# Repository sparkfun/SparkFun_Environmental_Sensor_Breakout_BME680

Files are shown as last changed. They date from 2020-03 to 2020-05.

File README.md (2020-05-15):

SparkFun Environmental Sensor - BME680 (Qwiic)
========================================

SparkFun Environmental Sensor - BME680 (Qwiic) (https://www.sparkfun.com/products/16466)

[*SparkFun Environmental Sensor - BME680 (Qwiic) (SEN-16466)*](https://www.sparkfun.com/products/16466)

The Environmental Sensor - BME680 (Qwiic) is a powerful 4-in-1 environmental sensor that communicates over I<sup>2</sup>C or SPI. The BME680 combines a gas sensor with temperature, humidity and barometric pressure sensors for a complete environmental sensor in a tiny package.

Repository Contents
-------------------
* **/Hardware** - Eagle design files (.brd, .sch)
* **/Production** - Production panel files (.brd)

Documentation
--------------
* **[Hookup Guide](https://learn.sparkfun.com/tutorials/environmental-sensor---bme680-qwiic-hookup-guide)** - Basic hookup guide for the SparkFun Environmental Sensor - BME680 (Qwiic).
* **[BME680 Arduino Library](https://github.com/SV-Zanshin/BME680)** - Arduino library created by SV-Zanshin for the BME680 Environmental Sensor.
* **[SparkFun Fritzing repo](https://github.com/sparkfun/Fritzing_Parts)** - Fritzing diagrams for SparkFun products.
* **[SparkFun 3D Model repo](https://github.com/sparkfun/3D_Models)** - 3D models of SparkFun products. 

Product Versions
----------------
* [SPX-14570](https://www.sparkfun.com/products/14570)- Original SparkX Release.
* [SEN-16466](https://www.sparkfun.com/products/16466)- SparkFun release.

License Information
-------------------

This product is _**open source**_! 

Please review the LICENSE.md file for license information. 

If you have any questions or concerns on licensing, please contact technical support on our [SparkFun forums](https://forum.sparkfun.com/viewforum.php?f=152).

Distributed as-is; no warranty is given.

- Your friends at SparkFun.

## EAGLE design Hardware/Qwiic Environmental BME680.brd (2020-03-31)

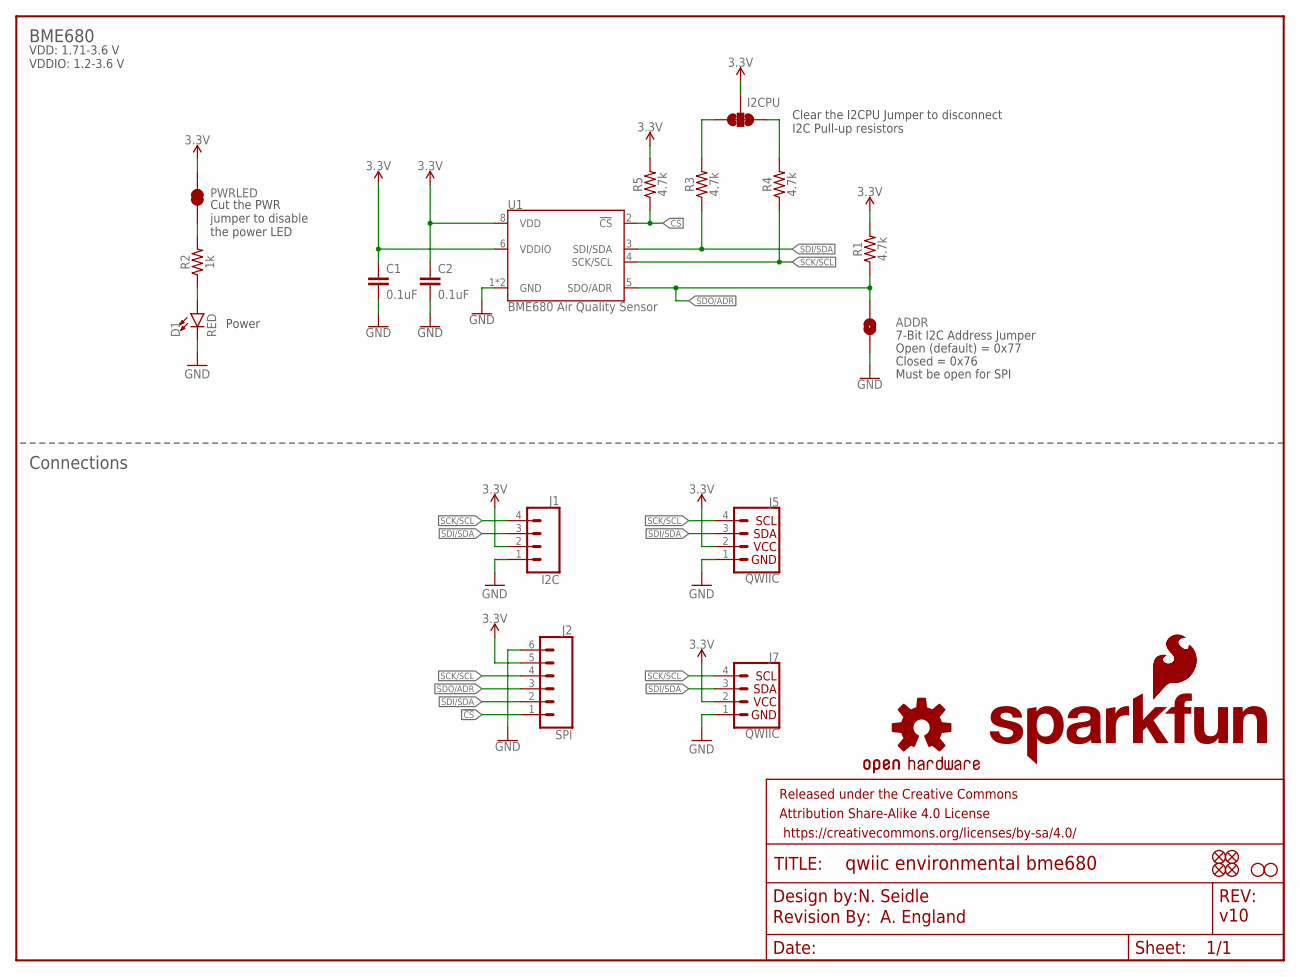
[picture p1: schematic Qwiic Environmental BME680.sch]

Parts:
ADDR: JUMPER-SMT_2_NO_SILK; SMT-JUMPER_2_NO_SILK
C1, C2: 0.1uF; 0603
D1: RED; LED-0603
FD1, FD2, FD3, FD4: FIDUCIALUFIDUCIAL; FIDUCIAL-MICRO
FRAME1: FRAME-LETTER; CREATIVE_COMMONS
H1, H2: STAND-OFFTIGHT; STAND-OFF-TIGHT
I2CPU: I2C PU; SMT-JUMPER_3_2-NC_TRACE_SILK
J1: I2C; 1X04_NO_SILK
J2: SPI; 1X06_NO_SILK
J5, J7: QWIIC; JST04_1MM_RA
LOGO1: OSHW-LOGOMINI; OSHW-LOGO-MINI
LOGO2: SFE_LOGO_NAME_FLAME.1_INCH; SFE_LOGO_NAME_FLAME_.1
LOGO3: REVISION
LOGO4: SFE_LOGO_FLAME.1_INCH; SFE_LOGO_FLAME_.1
PWRLED: JUMPER-SMT_2_NC_TRACE_SILK; SMT-JUMPER_2_NC_TRACE_SILK
R1, R3, R4, R5: 4.7k; 0603@1
R2: 1k; 0603
U1: BME680 Air Quality Sensor; LGA3.0X3.0

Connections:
3.3V: C1.1, C2.1, I2CPU.2, J1.2, J2.5, J5.2, J7.2, PWRLED.2, R1.2, R5.2, U1.6 (VDDIO), U1.8 (VDD)
!CS: J2.1, R5.1, U1.2 (!CS)
GND: ADDR.1, C1.2, C2.2, D1.C, J1.1, J2.6, J5.1, J7.1, U1.1 (GND), U1.7 (GND)
unnamed: PWRLED.1, R2.2
unnamed: D1.A, R2.1
unnamed: I2CPU.3, R3.2
unnamed: I2CPU.1, R4.2
SCK/SCL: J1.4, J2.4, J5.4, J7.4, R4.1, U1.4 (SCK/SCL)
SDI/SDA: J1.3, J2.2, J5.3, J7.3, R3.1, U1.3 (SDI/SDA)
SDO/ADR: ADDR.2, J2.3, R1.1, U1.5 (SDO/ADR)

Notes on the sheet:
v10
7-Bit I2C Address Jumper
Open (default) = 0x77
Closed = 0x76
N. Seidle
BME680
Connections
A. England
VDD: 1.71-3.6 V VDDIO: 1.2-3.6 V
Must be open for SPI
Clear the I2CPU Jumper to disconnect I2C Pull-up resistors
Power
Cut the PWR jumper to disable the power LED

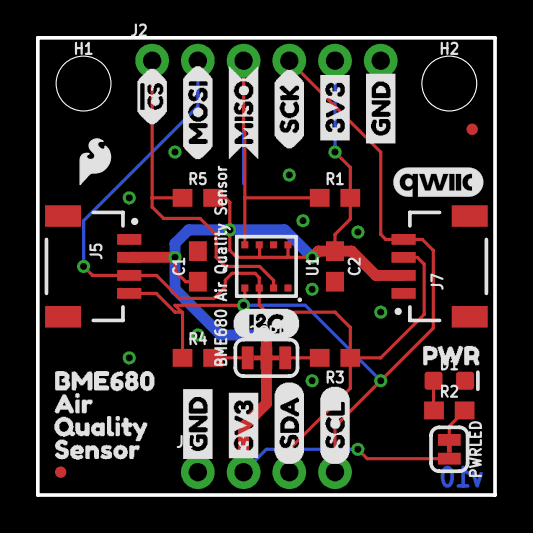
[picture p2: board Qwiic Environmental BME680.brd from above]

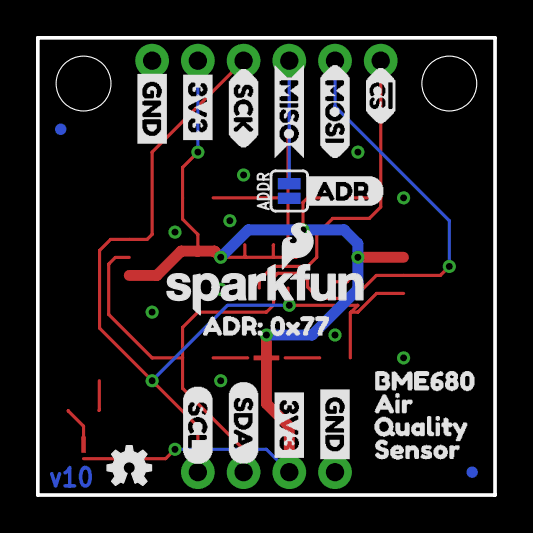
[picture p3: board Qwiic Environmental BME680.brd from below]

Board: 2 copper layers, 25.4 x 25.4 mm, 60 parts (21 on the bottom side), 10 nets.

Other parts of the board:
U$1, U$2: MISO_O
U$3, U$4: !CS_I
U$5, U$6: MOSI_I
U$7, U$8: SCK_I
U$9, U$10, U$16, U$17: 3V3_P
U$11, U$12, U$13, U$14: GND_P
U$15: I2C
U$18, U$19: SDA_IO
U$20, U$21: SCL_IO
U$22, U$26: BME6800
U$23, U$27: AIR1
U$24, U$28: QUALITY2
U$25, U$29: SENSOR3
U$30: ADR4
U$32: QWIIC_5MM
U$33: ADR#_0X770
U$34: PWR_TO

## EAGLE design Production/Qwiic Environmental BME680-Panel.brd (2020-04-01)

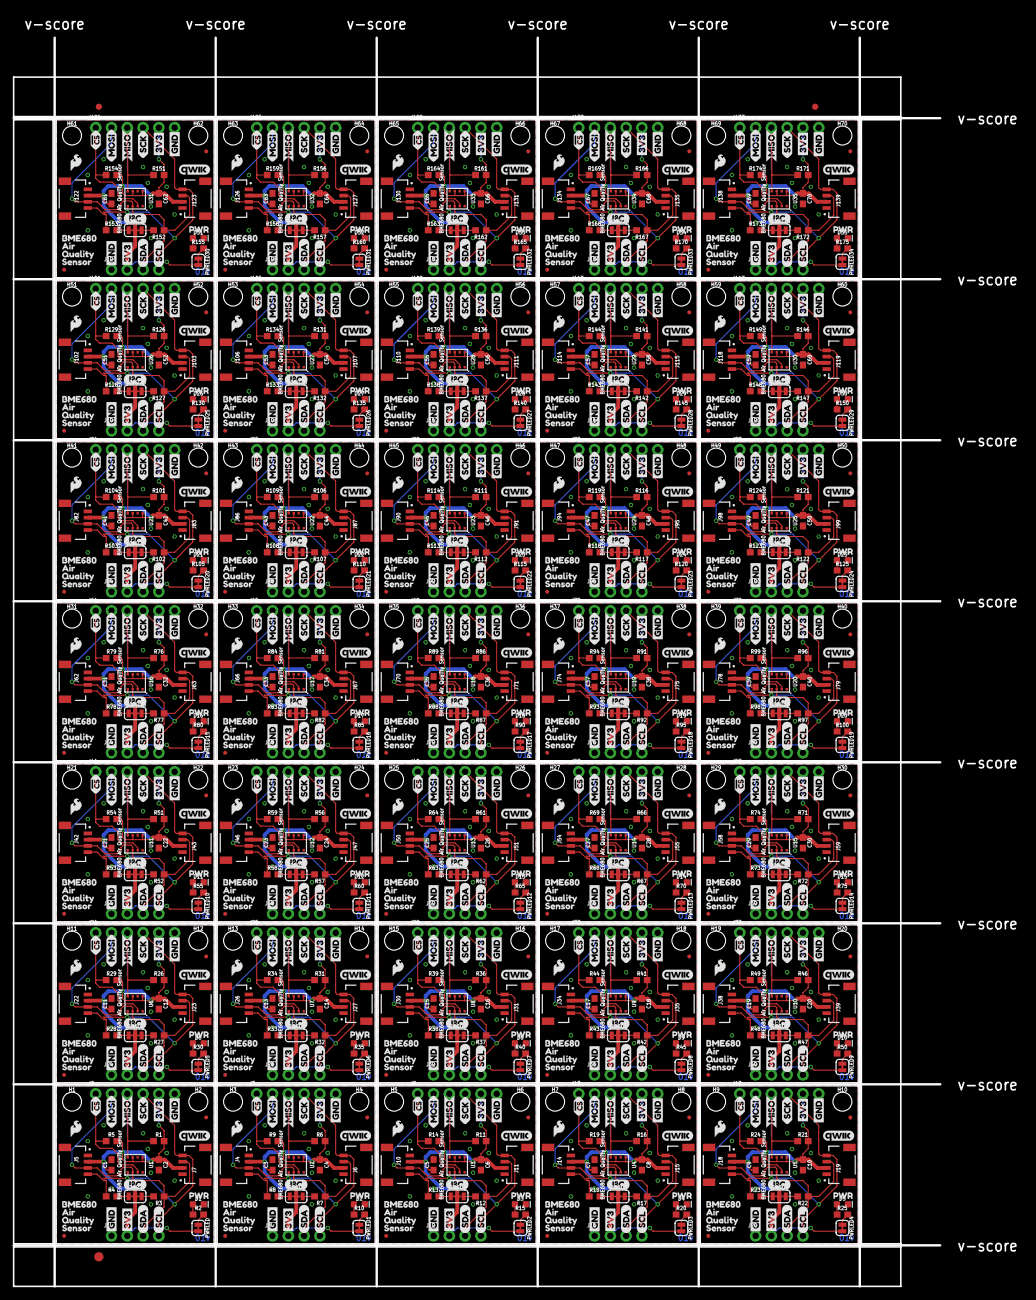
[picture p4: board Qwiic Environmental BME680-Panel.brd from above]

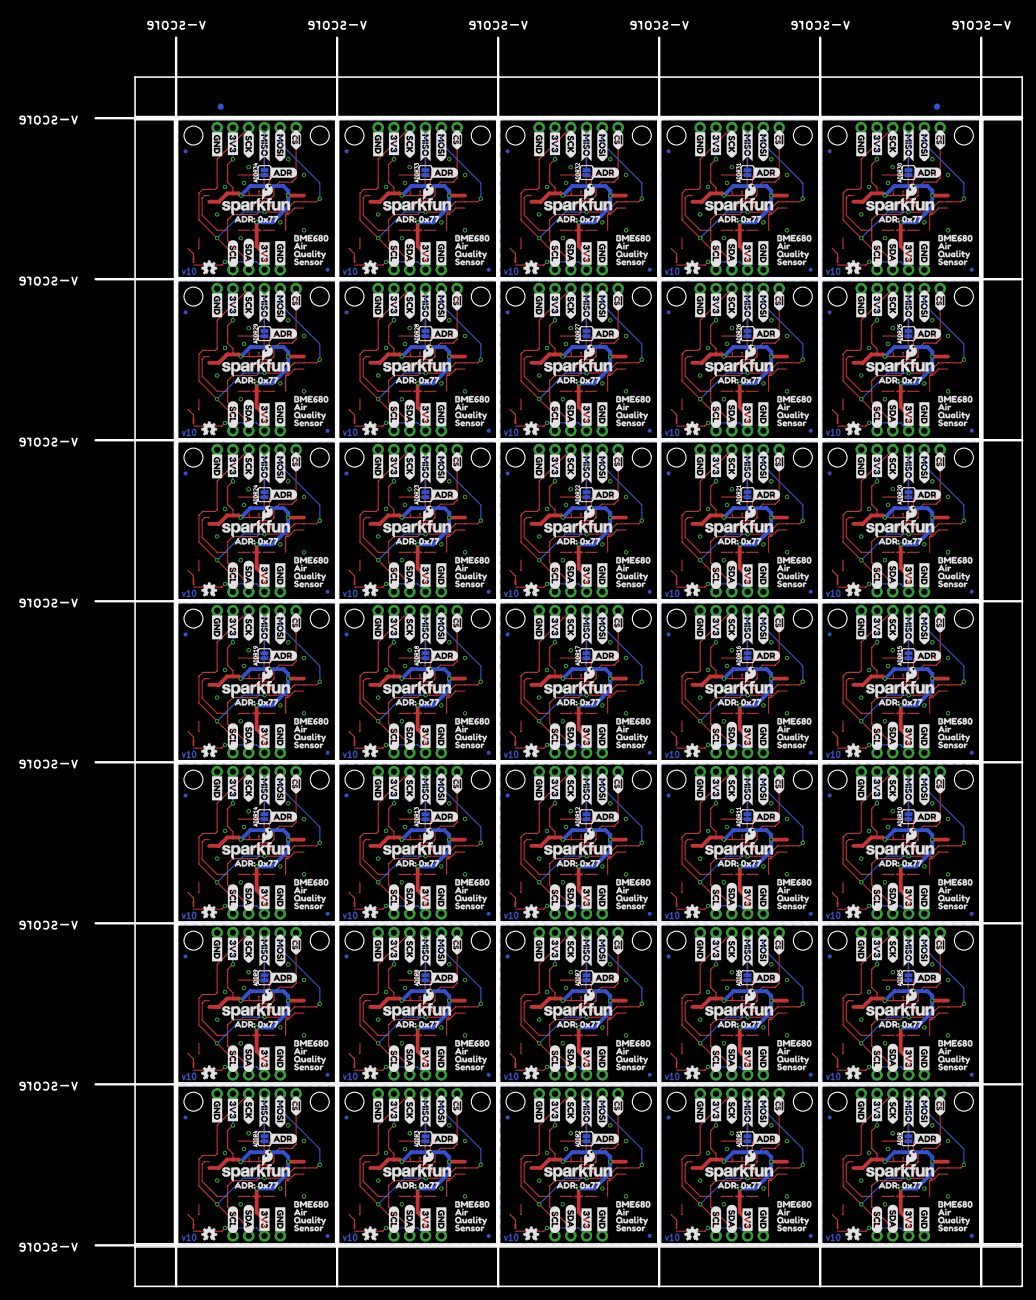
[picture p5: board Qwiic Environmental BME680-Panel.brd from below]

Board: 2 copper layers, 149.1 x 200.9 mm, 2070 parts (737 on the bottom side), 350 nets.

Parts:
ADDR, ADDR1, ADDR2, ADDR3, ADDR4, ADDR5, ADDR6, ADDR7, ADDR8, ADDR9, ADDR10, ADDR11, ADDR12, ADDR13, ADDR14, ADDR15, ADDR16, ADDR17, ADDR18, ADDR19, ADDR20, ADDR21, ADDR22, ADDR23, ADDR24, ADDR25, ADDR26, ADDR27, ADDR28, ADDR29, ADDR30, ADDR31, ADDR32, ADDR33, ADDR34: JUMPER-SMT_2_NO_SILK; SMT-JUMPER_2_NO_SILK
C1, C2, C3, C4, C5, C6, C7, C8, C9, C10, C11, C12, C13, C14, C15, C16, C17, C18, C19, C20, C21, C22, C23, C24, C25, C26, C27, C28, C29, C30, C31, C32, C33, C34, C35, C36, C37, C38, C39, C40, C41, C42, C43, C44, C45, C46, C47, C48, C49, C50, C51, C52, C53, C54, C55, C56, C57, C58, C59, C60, C61, C62, C63, C64, C65, C66, C67, C68, C69, C70: 0.1uF; 0603
D1, D2, D3, D4, D5, D6, D7, D8, D9, D10, D11, D12, D13, D14, D15, D16, D17, D18, D19, D20, D21, D22, D23, D24, D25, D26, D27, D28, D29, D30, D31, D32, D33, D34, D35: RED; LED-0603
E$1, E$2, E$3, E$4: FIDUCIAL-1X2
E$5: FIDUCIAL-1.5X3
FD1, FD2, FD3, FD4, FD5, FD6, FD7, FD8, FD9, FD10, FD11, FD12, FD13, FD14, FD15, FD16, FD17, FD18, FD19, FD20, FD21, FD22, FD23, FD24, FD25, FD26, FD27, FD28, FD29, FD30, FD31, FD32, FD33, FD34, FD35, FD36, FD37, FD38, FD39, FD40, FD41, FD42, FD43, FD44, FD45, FD46, FD47, FD48, FD49, FD50, FD51, FD52, FD53, FD54, FD55, FD56, FD57, FD58, FD59, FD60, FD61, FD62, FD63, FD64, FD65, FD66, FD67, FD68, FD69, FD70, FD71, FD72, FD73, FD74, FD75, FD76, FD77, FD78, FD79, FD80, FD81, FD82, FD83, FD84, FD85, FD86, FD87, FD88, FD89, FD90, FD91, FD92, FD93, FD94, FD95, FD96, FD97, FD98, FD99, FD100, FD101, FD102, FD103, FD104, FD105, FD106, FD107, FD108, FD109, FD110, FD111, FD112, FD113, FD114, FD115, FD116, FD117, FD118, FD119, FD120, FD121, FD122, FD123, FD124, FD125, FD126, FD127, FD128, FD129, FD130, FD131, FD132, FD133, FD134, FD135, FD136, FD137, FD138, FD139, FD140: FIDUCIALUFIDUCIAL; FIDUCIAL-MICRO
H1, H2, H3, H4, H5, H6, H7, H8, H9, H10, H11, H12, H13, H14, H15, H16, H17, H18, H19, H20, H21, H22, H23, H24, H25, H26, H27, H28, H29, H30, H31, H32, H33, H34, H35, H36, H37, H38, H39, H40, H41, H42, H43, H44, H45, H46, H47, H48, H49, H50, H51, H52, H53, H54, H55, H56, H57, H58, H59, H60, H61, H62, H63, H64, H65, H66, H67, H68, H69, H70: STAND-OFFTIGHT; STAND-OFF-TIGHT
I2CPU, I2CPU1, I2CPU2, I2CPU3, I2CPU4, I2CPU5, I2CPU6, I2CPU7, I2CPU8, I2CPU9, I2CPU10, I2CPU11, I2CPU12, I2CPU13, I2CPU14, I2CPU15, I2CPU16, I2CPU17, I2CPU18, I2CPU19, I2CPU20, I2CPU21, I2CPU22, I2CPU23, I2CPU24, I2CPU25, I2CPU26, I2CPU27, I2CPU28, I2CPU29, I2CPU30, I2CPU31, I2CPU32, I2CPU33, I2CPU34: I2C PU; SMT-JUMPER_3_2-NC_TRACE_SILK
J1, J8, J12, J16, J20, J24, J28, J32, J36, J40, J44, J48, J52, J56, J60, J64, J68, J72, J76, J80, J84, J88, J92, J96, J100, J104, J108, J112, J116, J120, J124, J128, J132, J136, J140: I2C; 1X04_NO_SILK
J2, J3, J9, J13, J17, J21, J25, J29, J33, J37, J41, J45, J49, J53, J57, J61, J65, J69, J73, J77, J81, J85, J89, J93, J97, J101, J105, J109, J113, J117, J121, J125, J129, J133, J137: SPI; 1X06_NO_SILK
J4, J5, J6, J7, J10, J11, J14, J15, J18, J19, J22, J23, J26, J27, J30, J31, J34, J35, J38, J39, J42, J43, J46, J47, J50, J51, J54, J55, J58, J59, J62, J63, J66, J67, J70, J71, J74, J75, J78, J79, J82, J83, J86, J87, J90, J91, J94, J95, J98, J99, J102, J103, J106, J107, J110, J111, J114, J115, J118, J119, J122, J123, J126, J127, J130, J131, J134, J135, J138, J139: QWIIC; JST04_1MM_RA
LOGO1, LOGO5, LOGO9, LOGO13, LOGO17, LOGO21, LOGO25, LOGO29, LOGO33, LOGO37, LOGO41, LOGO45, LOGO49, LOGO53, LOGO57, LOGO61, LOGO65, LOGO69, LOGO73, LOGO77, LOGO81, LOGO85, LOGO89, LOGO93, LOGO97, LOGO101, LOGO105, LOGO109, LOGO113, LOGO117, LOGO121, LOGO125, LOGO129, LOGO133, LOGO137: OSHW-LOGOMINI; OSHW-LOGO-MINI
LOGO2, LOGO7, LOGO11, LOGO15, LOGO19, LOGO23, LOGO27, LOGO31, LOGO35, LOGO39, LOGO43, LOGO47, LOGO51, LOGO55, LOGO59, LOGO63, LOGO67, LOGO71, LOGO75, LOGO79, LOGO83, LOGO87, LOGO91, LOGO95, LOGO99, LOGO103, LOGO107, LOGO111, LOGO115, LOGO119, LOGO123, LOGO127, LOGO131, LOGO135, LOGO139: SFE_LOGO_NAME_FLAME.1_INCH; SFE_LOGO_NAME_FLAME_.1
LOGO3, LOGO6, LOGO10, LOGO14, LOGO18, LOGO22, LOGO26, LOGO30, LOGO34, LOGO38, LOGO42, LOGO46, LOGO50, LOGO54, LOGO58, LOGO62, LOGO66, LOGO70, LOGO74, LOGO78, LOGO82, LOGO86, LOGO90, LOGO94, LOGO98, LOGO102, LOGO106, LOGO110, LOGO114, LOGO118, LOGO122, LOGO126, LOGO130, LOGO134, LOGO138: REVISION
LOGO4, LOGO8, LOGO12, LOGO16, LOGO20, LOGO24, LOGO28, LOGO32, LOGO36, LOGO40, LOGO44, LOGO48, LOGO52, LOGO56, LOGO60, LOGO64, LOGO68, LOGO72, LOGO76, LOGO80, LOGO84, LOGO88, LOGO92, LOGO96, LOGO100, LOGO104, LOGO108, LOGO112, LOGO116, LOGO120, LOGO124, LOGO128, LOGO132, LOGO136, LOGO140: SFE_LOGO_FLAME.1_INCH; SFE_LOGO_FLAME_.1
PWRLED, PWRLED1, PWRLED2, PWRLED3, PWRLED4, PWRLED5, PWRLED6, PWRLED7, PWRLED8, PWRLED9, PWRLED10, PWRLED11, PWRLED12, PWRLED13, PWRLED14, PWRLED15, PWRLED16, PWRLED17, PWRLED18, PWRLED19, PWRLED20, PWRLED21, PWRLED22, PWRLED23, PWRLED24, PWRLED25, PWRLED26, PWRLED27, PWRLED28, PWRLED29, PWRLED30, PWRLED31, PWRLED32, PWRLED33, PWRLED34: JUMPER-SMT_2_NC_TRACE_SILK; SMT-JUMPER_2_NC_TRACE_SILK
R1, R3, R4, R5, R6, R7, R8, R9, R11, R12, R13, R14, R16, R17, R18, R19, R21, R22, R23, R24, R26, R27, R28, R29, R31, R32, R33, R34, R36, R37, R38, R39, R41, R42, R43, R44, R46, R47, R48, R49, R51, R52, R53, R54, R56, R57, R58, R59, R61, R62, R63, R64, R66, R67, R68, R69, R71, R72, R73, R74, R76, R77, R78, R79, R81, R82, R83, R84, R86, R87, R88, R89, R91, R92, R93, R94, R96, R97, R98, R99, R101, R102, R103, R104, R106, R107, R108, R109, R111, R112, R113, R114, R116, R117, R118, R119, R121, R122, R123, R124, R126, R127, R128, R129, R131, R132, R133, R134, R136, R137, R138, R139, R141, R142, R143, R144, R146, R147, R148, R149, R151, R152, R153, R154, R156, R157, R158, R159, R161, R162, R163, R164, R166, R167, R168, R169, R171, R172, R173, R174: 4.7k; 0603@1
R2, R10, R15, R20, R25, R30, R35, R40, R45, R50, R55, R60, R65, R70, R75, R80, R85, R90, R95, R100, R105, R110, R115, R120, R125, R130, R135, R140, R145, R150, R155, R160, R165, R170, R175: 1k; 0603
U1, U2, U3, U4, U5, U6, U7, U8, U9, U10, U11, U12, U13, U14, U15, U16, U17, U18, U19, U20, U21, U22, U23, U24, U25, U26, U27, U28, U29, U30, U31, U32, U33, U34, U35: BME680 Air Quality Sensor; LGA3.0X3.0
U$1, U$2, U$38, U$39, U$71, U$72, U$104, U$105, U$137, U$138, U$170, U$171, U$203, U$204, U$236, U$237, U$269, U$270, U$302, U$303, U$335, U$336, U$368, U$369, U$401, U$402, U$434, U$435, U$467, U$468, U$500, U$501, U$533, U$534, U$566, U$567, U$599, U$600, U$632, U$633, U$665, U$666, U$698, U$699, U$731, U$732, U$764, U$765, U$797, U$798, U$830, U$831, U$863, U$864, U$896, U$897, U$929, U$930, U$962, U$963, U$995, U$996, U$1028, U$1029, U$1061, U$1062, U$1094, U$1095, U$1127, U$1128: MISO_O
U$3, U$4, U$31, U$35, U$67, U$68, U$100, U$101, U$133, U$134, U$166, U$167, U$199, U$200, U$232, U$233, U$265, U$266, U$298, U$299, U$331, U$332, U$364, U$365, U$397, U$398, U$430, U$431, U$463, U$464, U$496, U$497, U$529, U$530, U$562, U$563, U$595, U$596, U$628, U$629, U$661, U$662, U$694, U$695, U$727, U$728, U$760, U$761, U$793, U$794, U$826, U$827, U$859, U$860, U$892, U$893, U$925, U$926, U$958, U$959, U$991, U$992, U$1024, U$1025, U$1057, U$1058, U$1090, U$1091, U$1123, U$1124: !CS_I
U$5, U$6, U$36, U$37, U$69, U$70, U$102, U$103, U$135, U$136, U$168, U$169, U$201, U$202, U$234, U$235, U$267, U$268, U$300, U$301, U$333, U$334, U$366, U$367, U$399, U$400, U$432, U$433, U$465, U$466, U$498, U$499, U$531, U$532, U$564, U$565, U$597, U$598, U$630, U$631, U$663, U$664, U$696, U$697, U$729, U$730, U$762, U$763, U$795, U$796, U$828, U$829, U$861, U$862, U$894, U$895, U$927, U$928, U$960, U$961, U$993, U$994, U$1026, U$1027, U$1059, U$1060, U$1092, U$1093, U$1125, U$1126: MOSI_I
U$7, U$8, U$40, U$41, U$73, U$74, U$106, U$107, U$139, U$140, U$172, U$173, U$205, U$206, U$238, U$239, U$271, U$272, U$304, U$305, U$337, U$338, U$370, U$371, U$403, U$404, U$436, U$437, U$469, U$470, U$502, U$503, U$535, U$536, U$568, U$569, U$601, U$602, U$634, U$635, U$667, U$668, U$700, U$701, U$733, U$734, U$766, U$767, U$799, U$800, U$832, U$833, U$865, U$866, U$898, U$899, U$931, U$932, U$964, U$965, U$997, U$998, U$1030, U$1031, U$1063, U$1064, U$1096, U$1097, U$1129, U$1130: SCK_I
U$9, U$10, U$16, U$17, U$42, U$43, U$49, U$50, U$75, U$76, U$82, U$83, U$108, U$109, U$115, U$116, U$141, U$142, U$148, U$149, U$174, U$175, U$181, U$182, U$207, U$208, U$214, U$215, U$240, U$241, U$247, U$248, U$273, U$274, U$280, U$281, U$306, U$307, U$313, U$314, U$339, U$340, U$346, U$347, U$372, U$373, U$379, U$380, U$405, U$406, U$412, U$413, U$438, U$439, U$445, U$446, U$471, U$472, U$478, U$479, U$504, U$505, U$511, U$512, U$537, U$538, U$544, U$545, U$570, U$571, U$577, U$578, U$603, U$604, U$610, U$611, U$636, U$637, U$643, U$644, U$669, U$670, U$676, U$677, U$702, U$703, U$709, U$710, U$735, U$736, U$742, U$743, U$768, U$769, U$775, U$776, U$801, U$802, U$808, U$809, U$834, U$835, U$841, U$842, U$867, U$868, U$874, U$875, U$900, U$901, U$907, U$908, U$933, U$934, U$940, U$941, U$966, U$967, U$973, U$974, U$999, U$1000, U$1006, U$1007, U$1032, U$1033, U$1039, U$1040, U$1065, U$1066, U$1072, U$1073, U$1098, U$1099, U$1105, U$1106, U$1131, U$1132, U$1138, U$1139: 3V3_P
U$11, U$12, U$13, U$14, U$44, U$45, U$46, U$47, U$77, U$78, U$79, U$80, U$110, U$111, U$112, U$113, U$143, U$144, U$145, U$146, U$176, U$177, U$178, U$179, U$209, U$210, U$211, U$212, U$242, U$243, U$244, U$245, U$275, U$276, U$277, U$278, U$308, U$309, U$310, U$311, U$341, U$342, U$343, U$344, U$374, U$375, U$376, U$377, U$407, U$408, U$409, U$410, U$440, U$441, U$442, U$443, U$473, U$474, U$475, U$476, U$506, U$507, U$508, U$509, U$539, U$540, U$541, U$542, U$572, U$573, U$574, U$575, U$605, U$606, U$607, U$608, U$638, U$639, U$640, U$641, U$671, U$672, U$673, U$674, U$704, U$705, U$706, U$707, U$737, U$738, U$739, U$740, U$770, U$771, U$772, U$773, U$803, U$804, U$805, U$806, U$836, U$837, U$838, U$839, U$869, U$870, U$871, U$872, U$902, U$903, U$904, U$905, U$935, U$936, U$937, U$938, U$968, U$969, U$970, U$971, U$1001, U$1002, U$1003, U$1004, U$1034, U$1035, U$1036, U$1037, U$1067, U$1068, U$1069, U$1070, U$1100, U$1101, U$1102, U$1103, U$1133, U$1134, U$1135, U$1136: GND_P
U$15, U$48, U$81, U$114, U$147, U$180, U$213, U$246, U$279, U$312, U$345, U$378, U$411, U$444, U$477, U$510, U$543, U$576, U$609, U$642, U$675, U$708, U$741, U$774, U$807, U$840, U$873, U$906, U$939, U$972, U$1005, U$1038, U$1071, U$1104, U$1137: I2C
U$18, U$19, U$51, U$52, U$84, U$85, U$117, U$118, U$150, U$151, U$183, U$184, U$216, U$217, U$249, U$250, U$282, U$283, U$315, U$316, U$348, U$349, U$381, U$382, U$414, U$415, U$447, U$448, U$480, U$481, U$513, U$514, U$546, U$547, U$579, U$580, U$612, U$613, U$645, U$646, U$678, U$679, U$711, U$712, U$744, U$745, U$777, U$778, U$810, U$811, U$843, U$844, U$876, U$877, U$909, U$910, U$942, U$943, U$975, U$976, U$1008, U$1009, U$1041, U$1042, U$1074, U$1075, U$1107, U$1108, U$1140, U$1141: SDA_IO
U$20, U$21, U$53, U$54, U$86, U$87, U$119, U$120, U$152, U$153, U$185, U$186, U$218, U$219, U$251, U$252, U$284, U$285, U$317, U$318, U$350, U$351, U$383, U$384, U$416, U$417, U$449, U$450, U$482, U$483, U$515, U$516, U$548, U$549, U$581, U$582, U$614, U$615, U$647, U$648, U$680, U$681, U$713, U$714, U$746, U$747, U$779, U$780, U$812, U$813, U$845, U$846, U$878, U$879, U$911, U$912, U$944, U$945, U$977, U$978, U$1010, U$1011, U$1043, U$1044, U$1076, U$1077, U$1109, U$1110, U$1142, U$1143: SCL_IO
U$22, U$26, U$55, U$59, U$88, U$92, U$121, U$125, U$154, U$158, U$187, U$191, U$220, U$224, U$253, U$257, U$286, U$290, U$319, U$323, U$352, U$356, U$385, U$389, U$418, U$422, U$451, U$455, U$484, U$488, U$517, U$521, U$550, U$554, U$583, U$587, U$616, U$620, U$649, U$653, U$682, U$686, U$715, U$719, U$748, U$752, U$781, U$785, U$814, U$818, U$847, U$851, U$880, U$884, U$913, U$917, U$946, U$950, U$979, U$983, U$1012, U$1016, U$1045, U$1049, U$1078, U$1082, U$1111, U$1115, U$1144, U$1148: BME6800
U$23, U$27, U$56, U$60, U$89, U$93, U$122, U$126, U$155, U$159, U$188, U$192, U$221, U$225, U$254, U$258, U$287, U$291, U$320, U$324, U$353, U$357, U$386, U$390, U$419, U$423, U$452, U$456, U$485, U$489, U$518, U$522, U$551, U$555, U$584, U$588, U$617, U$621, U$650, U$654, U$683, U$687, U$716, U$720, U$749, U$753, U$782, U$786, U$815, U$819, U$848, U$852, U$881, U$885, U$914, U$918, U$947, U$951, U$980, U$984, U$1013, U$1017, U$1046, U$1050, U$1079, U$1083, U$1112, U$1116, U$1145, U$1149: AIR1
U$24, U$28, U$57, U$61, U$90, U$94, U$123, U$127, U$156, U$160, U$189, U$193, U$222, U$226, U$255, U$259, U$288, U$292, U$321, U$325, U$354, U$358, U$387, U$391, U$420, U$424, U$453, U$457, U$486, U$490, U$519, U$523, U$552, U$556, U$585, U$589, U$618, U$622, U$651, U$655, U$684, U$688, U$717, U$721, U$750, U$754, U$783, U$787, U$816, U$820, U$849, U$853, U$882, U$886, U$915, U$919, U$948, U$952, U$981, U$985, U$1014, U$1018, U$1047, U$1051, U$1080, U$1084, U$1113, U$1117, U$1146, U$1150: QUALITY2
U$25, U$29, U$58, U$62, U$91, U$95, U$124, U$128, U$157, U$161, U$190, U$194, U$223, U$227, U$256, U$260, U$289, U$293, U$322, U$326, U$355, U$359, U$388, U$392, U$421, U$425, U$454, U$458, U$487, U$491, U$520, U$524, U$553, U$557, U$586, U$590, U$619, U$623, U$652, U$656, U$685, U$689, U$718, U$722, U$751, U$755, U$784, U$788, U$817, U$821, U$850, U$854, U$883, U$887, U$916, U$920, U$949, U$953, U$982, U$986, U$1015, U$1019, U$1048, U$1052, U$1081, U$1085, U$1114, U$1118, U$1147, U$1151: SENSOR3
U$30, U$63, U$96, U$129, U$162, U$195, U$228, U$261, U$294, U$327, U$360, U$393, U$426, U$459, U$492, U$525, U$558, U$591, U$624, U$657, U$690, U$723, U$756, U$789, U$822, U$855, U$888, U$921, U$954, U$987, U$1020, U$1053, U$1086, U$1119, U$1152: ADR4
U$32, U$65, U$98, U$131, U$164, U$197, U$230, U$263, U$296, U$329, U$362, U$395, U$428, U$461, U$494, U$527, U$560, U$593, U$626, U$659, U$692, U$725, U$758, U$791, U$824, U$857, U$890, U$923, U$956, U$989, U$1022, U$1055, U$1088, U$1121, U$1154: QWIIC_5MM
U$33, U$64, U$97, U$130, U$163, U$196, U$229, U$262, U$295, U$328, U$361, U$394, U$427, U$460, U$493, U$526, U$559, U$592, U$625, U$658, U$691, U$724, U$757, U$790, U$823, U$856, U$889, U$922, U$955, U$988, U$1021, U$1054, U$1087, U$1120, U$1153: ADR#_0X770
U$34, U$66, U$99, U$132, U$165, U$198, U$231, U$264, U$297, U$330, U$363, U$396, U$429, U$462, U$495, U$528, U$561, U$594, U$627, U$660, U$693, U$726, U$759, U$792, U$825, U$858, U$891, U$924, U$957, U$990, U$1023, U$1056, U$1089, U$1122, U$1155: PWR_TO

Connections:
3.3V: C1.1, C2.1, I2CPU.2, J1.2, J2.5, J5.2, J7.2, PWRLED.2, R1.2, R5.2, U1.6, U1.8
3.3V1: C3.1, C4.1, I2CPU1.2, J3.5, J4.2, J6.2, J8.2, PWRLED1.2, R6.2, R9.2, U2.6, U2.8
3.3V2: C5.1, C6.1, I2CPU2.2, J9.5, J10.2, J11.2, J12.2, PWRLED2.2, R11.2, R14.2, U3.6, U3.8
3.3V3: C7.1, C8.1, I2CPU3.2, J13.5, J14.2, J15.2, J16.2, PWRLED3.2, R16.2, R19.2, U4.6, U4.8
3.3V4: C9.1, C10.1, I2CPU4.2, J17.5, J18.2, J19.2, J20.2, PWRLED4.2, R21.2, R24.2, U5.6, U5.8
3.3V5: C11.1, C12.1, I2CPU5.2, J21.5, J22.2, J23.2, J24.2, PWRLED5.2, R26.2, R29.2, U6.6, U6.8
3.3V6: C13.1, C14.1, I2CPU6.2, J25.5, J26.2, J27.2, J28.2, PWRLED6.2, R31.2, R34.2, U7.6, U7.8
3.3V7: C15.1, C16.1, I2CPU7.2, J29.5, J30.2, J31.2, J32.2, PWRLED7.2, R36.2, R39.2, U8.6, U8.8
3.3V8: C17.1, C18.1, I2CPU8.2, J33.5, J34.2, J35.2, J36.2, PWRLED8.2, R41.2, R44.2, U9.6, U9.8
3.3V9: C19.1, C20.1, I2CPU9.2, J37.5, J38.2, J39.2, J40.2, PWRLED9.2, R46.2, R49.2, U10.6, U10.8
3.3V10: C21.1, C22.1, I2CPU10.2, J41.5, J42.2, J43.2, J44.2, PWRLED10.2, R51.2, R54.2, U11.6, U11.8
3.3V11: C23.1, C24.1, I2CPU11.2, J45.5, J46.2, J47.2, J48.2, PWRLED11.2, R56.2, R59.2, U12.6, U12.8
3.3V12: C25.1, C26.1, I2CPU12.2, J49.5, J50.2, J51.2, J52.2, PWRLED12.2, R61.2, R64.2, U13.6, U13.8
3.3V13: C27.1, C28.1, I2CPU13.2, J53.5, J54.2, J55.2, J56.2, PWRLED13.2, R66.2, R69.2, U14.6, U14.8
3.3V14: C29.1, C30.1, I2CPU14.2, J57.5, J58.2, J59.2, J60.2, PWRLED14.2, R71.2, R74.2, U15.6, U15.8
3.3V15: C31.1, C32.1, I2CPU15.2, J61.5, J62.2, J63.2, J64.2, PWRLED15.2, R76.2, R79.2, U16.6, U16.8
3.3V16: C33.1, C34.1, I2CPU16.2, J65.5, J66.2, J67.2, J68.2, PWRLED16.2, R81.2, R84.2, U17.6, U17.8
3.3V17: C35.1, C36.1, I2CPU17.2, J69.5, J70.2, J71.2, J72.2, PWRLED17.2, R86.2, R89.2, U18.6, U18.8
3.3V18: C37.1, C38.1, I2CPU18.2, J73.5, J74.2, J75.2, J76.2, PWRLED18.2, R91.2, R94.2, U19.6, U19.8
3.3V19: C39.1, C40.1, I2CPU19.2, J77.5, J78.2, J79.2, J80.2, PWRLED19.2, R96.2, R99.2, U20.6, U20.8
3.3V20: C41.1, C42.1, I2CPU20.2, J81.5, J82.2, J83.2, J84.2, PWRLED20.2, R101.2, R104.2, U21.6, U21.8
3.3V21: C43.1, C44.1, I2CPU21.2, J85.5, J86.2, J87.2, J88.2, PWRLED21.2, R106.2, R109.2, U22.6, U22.8
3.3V22: C45.1, C46.1, I2CPU22.2, J89.5, J90.2, J91.2, J92.2, PWRLED22.2, R111.2, R114.2, U23.6, U23.8
3.3V23: C47.1, C48.1, I2CPU23.2, J93.5, J94.2, J95.2, J96.2, PWRLED23.2, R116.2, R119.2, U24.6, U24.8
3.3V24: C49.1, C50.1, I2CPU24.2, J97.5, J98.2, J99.2, J100.2, PWRLED24.2, R121.2, R124.2, U25.6, U25.8
3.3V25: C51.1, C52.1, I2CPU25.2, J101.5, J102.2, J103.2, J104.2, PWRLED25.2, R126.2, R129.2, U26.6, U26.8
3.3V26: C53.1, C54.1, I2CPU26.2, J105.5, J106.2, J107.2, J108.2, PWRLED26.2, R131.2, R134.2, U27.6, U27.8
3.3V27: C55.1, C56.1, I2CPU27.2, J109.5, J110.2, J111.2, J112.2, PWRLED27.2, R136.2, R139.2, U28.6, U28.8
3.3V28: C57.1, C58.1, I2CPU28.2, J113.5, J114.2, J115.2, J116.2, PWRLED28.2, R141.2, R144.2, U29.6, U29.8
3.3V29: C59.1, C60.1, I2CPU29.2, J117.5, J118.2, J119.2, J120.2, PWRLED29.2, R146.2, R149.2, U30.6, U30.8
3.3V30: C61.1, C62.1, I2CPU30.2, J121.5, J122.2, J123.2, J124.2, PWRLED30.2, R151.2, R154.2, U31.6, U31.8
3.3V31: C63.1, C64.1, I2CPU31.2, J125.5, J126.2, J127.2, J128.2, PWRLED31.2, R156.2, R159.2, U32.6, U32.8
3.3V32: C65.1, C66.1, I2CPU32.2, J129.5, J130.2, J131.2, J132.2, PWRLED32.2, R161.2, R164.2, U33.6, U33.8
3.3V33: C67.1, C68.1, I2CPU33.2, J133.5, J134.2, J135.2, J136.2, PWRLED33.2, R166.2, R169.2, U34.6, U34.8
3.3V34: C69.1, C70.1, I2CPU34.2, J137.5, J138.2, J139.2, J140.2, PWRLED34.2, R171.2, R174.2, U35.6, U35.8
!CS: J2.1, R5.1, U1.2
!CS1: J3.1, R9.1, U2.2
!CS2: J9.1, R14.1, U3.2
!CS3: J13.1, R19.1, U4.2
!CS4: J17.1, R24.1, U5.2
!CS5: J21.1, R29.1, U6.2
!CS6: J25.1, R34.1, U7.2
!CS7: J29.1, R39.1, U8.2
!CS8: J33.1, R44.1, U9.2
!CS9: J37.1, R49.1, U10.2
!CS10: J41.1, R54.1, U11.2
!CS11: J45.1, R59.1, U12.2
!CS12: J49.1, R64.1, U13.2
!CS13: J53.1, R69.1, U14.2
!CS14: J57.1, R74.1, U15.2
!CS15: J61.1, R79.1, U16.2
!CS16: J65.1, R84.1, U17.2
!CS17: J69.1, R89.1, U18.2
!CS18: J73.1, R94.1, U19.2
!CS19: J77.1, R99.1, U20.2
!CS20: J81.1, R104.1, U21.2
!CS21: J85.1, R109.1, U22.2
!CS22: J89.1, R114.1, U23.2
!CS23: J93.1, R119.1, U24.2
!CS24: J97.1, R124.1, U25.2
!CS25: J101.1, R129.1, U26.2
!CS26: J105.1, R134.1, U27.2
!CS27: J109.1, R139.1, U28.2
!CS28: J113.1, R144.1, U29.2
!CS29: J117.1, R149.1, U30.2
!CS30: J121.1, R154.1, U31.2
!CS31: J125.1, R159.1, U32.2
!CS32: J129.1, R164.1, U33.2
!CS33: J133.1, R169.1, U34.2
!CS34: J137.1, R174.1, U35.2
GND: ADDR.1, C1.2, C2.2, D1.C, J1.1, J2.6, J5.1, J7.1, U1.1, U1.7
GND1: ADDR1.1, C3.2, C4.2, D2.C, J3.6, J4.1, J6.1, J8.1, U2.1, U2.7
GND2: ADDR2.1, C5.2, C6.2, D3.C, J9.6, J10.1, J11.1, J12.1, U3.1, U3.7
GND3: ADDR3.1, C7.2, C8.2, D4.C, J13.6, J14.1, J15.1, J16.1, U4.1, U4.7
GND4: ADDR4.1, C9.2, C10.2, D5.C, J17.6, J18.1, J19.1, J20.1, U5.1, U5.7
GND5: ADDR5.1, C11.2, C12.2, D6.C, J21.6, J22.1, J23.1, J24.1, U6.1, U6.7
GND6: ADDR6.1, C13.2, C14.2, D7.C, J25.6, J26.1, J27.1, J28.1, U7.1, U7.7
GND7: ADDR7.1, C15.2, C16.2, D8.C, J29.6, J30.1, J31.1, J32.1, U8.1, U8.7
GND8: ADDR8.1, C17.2, C18.2, D9.C, J33.6, J34.1, J35.1, J36.1, U9.1, U9.7
GND9: ADDR9.1, C19.2, C20.2, D10.C, J37.6, J38.1, J39.1, J40.1, U10.1, U10.7
GND10: ADDR10.1, C21.2, C22.2, D11.C, J41.6, J42.1, J43.1, J44.1, U11.1, U11.7
GND11: ADDR11.1, C23.2, C24.2, D12.C, J45.6, J46.1, J47.1, J48.1, U12.1, U12.7
GND12: ADDR12.1, C25.2, C26.2, D13.C, J49.6, J50.1, J51.1, J52.1, U13.1, U13.7
GND13: ADDR13.1, C27.2, C28.2, D14.C, J53.6, J54.1, J55.1, J56.1, U14.1, U14.7
GND14: ADDR14.1, C29.2, C30.2, D15.C, J57.6, J58.1, J59.1, J60.1, U15.1, U15.7
GND15: ADDR15.1, C31.2, C32.2, D16.C, J61.6, J62.1, J63.1, J64.1, U16.1, U16.7
GND16: ADDR16.1, C33.2, C34.2, D17.C, J65.6, J66.1, J67.1, J68.1, U17.1, U17.7
GND17: ADDR17.1, C35.2, C36.2, D18.C, J69.6, J70.1, J71.1, J72.1, U18.1, U18.7
GND18: ADDR18.1, C37.2, C38.2, D19.C, J73.6, J74.1, J75.1, J76.1, U19.1, U19.7
GND19: ADDR19.1, C39.2, C40.2, D20.C, J77.6, J78.1, J79.1, J80.1, U20.1, U20.7
GND20: ADDR20.1, C41.2, C42.2, D21.C, J81.6, J82.1, J83.1, J84.1, U21.1, U21.7
GND21: ADDR21.1, C43.2, C44.2, D22.C, J85.6, J86.1, J87.1, J88.1, U22.1, U22.7
GND22: ADDR22.1, C45.2, C46.2, D23.C, J89.6, J90.1, J91.1, J92.1, U23.1, U23.7
GND23: ADDR23.1, C47.2, C48.2, D24.C, J93.6, J94.1, J95.1, J96.1, U24.1, U24.7
GND24: ADDR24.1, C49.2, C50.2, D25.C, J97.6, J98.1, J99.1, J100.1, U25.1, U25.7
GND25: ADDR25.1, C51.2, C52.2, D26.C, J101.6, J102.1, J103.1, J104.1, U26.1, U26.7
GND26: ADDR26.1, C53.2, C54.2, D27.C, J105.6, J106.1, J107.1, J108.1, U27.1, U27.7
GND27: ADDR27.1, C55.2, C56.2, D28.C, J109.6, J110.1, J111.1, J112.1, U28.1, U28.7
GND28: ADDR28.1, C57.2, C58.2, D29.C, J113.6, J114.1, J115.1, J116.1, U29.1, U29.7
GND29: ADDR29.1, C59.2, C60.2, D30.C, J117.6, J118.1, J119.1, J120.1, U30.1, U30.7
GND30: ADDR30.1, C61.2, C62.2, D31.C, J121.6, J122.1, J123.1, J124.1, U31.1, U31.7
GND31: ADDR31.1, C63.2, C64.2, D32.C, J125.6, J126.1, J127.1, J128.1, U32.1, U32.7
GND32: ADDR32.1, C65.2, C66.2, D33.C, J129.6, J130.1, J131.1, J132.1, U33.1, U33.7
GND33: ADDR33.1, C67.2, C68.2, D34.C, J133.6, J134.1, J135.1, J136.1, U34.1, U34.7
GND34: ADDR34.1, C69.2, C70.2, D35.C, J137.6, J138.1, J139.1, J140.1, U35.1, U35.7
unnamed: PWRLED.1, R2.2
unnamed: I2CPU1.3, R7.2
unnamed: D1.A, R2.1
unnamed: I2CPU.3, R3.2
unnamed: I2CPU.1, R4.2
unnamed: I2CPU1.1, R8.2
unnamed: D2.A, R10.1
unnamed: PWRLED1.1, R10.2
unnamed: I2CPU2.3, R12.2
unnamed: I2CPU2.1, R13.2
unnamed: D3.A, R15.1
unnamed: PWRLED2.1, R15.2
unnamed: I2CPU3.3, R17.2
unnamed: I2CPU3.1, R18.2
unnamed: D4.A, R20.1
unnamed: PWRLED3.1, R20.2
unnamed: I2CPU4.3, R22.2
unnamed: I2CPU4.1, R23.2
unnamed: D5.A, R25.1
unnamed: PWRLED4.1, R25.2
unnamed: I2CPU5.3, R27.2
unnamed: I2CPU5.1, R28.2
unnamed: D6.A, R30.1
unnamed: PWRLED5.1, R30.2
unnamed: I2CPU6.3, R32.2
unnamed: I2CPU6.1, R33.2
unnamed: D7.A, R35.1
unnamed: PWRLED6.1, R35.2
unnamed: I2CPU7.3, R37.2
unnamed: I2CPU7.1, R38.2
unnamed: D8.A, R40.1
unnamed: PWRLED7.1, R40.2
unnamed: I2CPU8.3, R42.2
unnamed: I2CPU8.1, R43.2
unnamed: D9.A, R45.1
unnamed: PWRLED8.1, R45.2
unnamed: I2CPU9.3, R47.2
unnamed: I2CPU9.1, R48.2
unnamed: D10.A, R50.1
unnamed: PWRLED9.1, R50.2
unnamed: I2CPU10.3, R52.2
unnamed: I2CPU10.1, R53.2
unnamed: D11.A, R55.1
unnamed: PWRLED10.1, R55.2
unnamed: I2CPU11.3, R57.2
unnamed: I2CPU11.1, R58.2
unnamed: D12.A, R60.1
unnamed: PWRLED11.1, R60.2
unnamed: I2CPU12.3, R62.2
unnamed: I2CPU12.1, R63.2
unnamed: D13.A, R65.1
unnamed: PWRLED12.1, R65.2
unnamed: I2CPU13.3, R67.2
unnamed: I2CPU13.1, R68.2
unnamed: D14.A, R70.1
unnamed: PWRLED13.1, R70.2
unnamed: I2CPU14.3, R72.2
unnamed: I2CPU14.1, R73.2
unnamed: D15.A, R75.1
unnamed: PWRLED14.1, R75.2
unnamed: I2CPU15.3, R77.2
unnamed: I2CPU15.1, R78.2
unnamed: D16.A, R80.1
unnamed: PWRLED15.1, R80.2
unnamed: I2CPU16.3, R82.2
unnamed: I2CPU16.1, R83.2
unnamed: D17.A, R85.1
unnamed: PWRLED16.1, R85.2
unnamed: I2CPU17.3, R87.2
unnamed: I2CPU17.1, R88.2
unnamed: D18.A, R90.1
unnamed: PWRLED17.1, R90.2
unnamed: I2CPU18.3, R92.2
unnamed: I2CPU18.1, R93.2
unnamed: D19.A, R95.1
unnamed: PWRLED18.1, R95.2
unnamed: I2CPU19.3, R97.2
unnamed: I2CPU19.1, R98.2
unnamed: D20.A, R100.1
unnamed: PWRLED19.1, R100.2
unnamed: I2CPU20.3, R102.2
unnamed: I2CPU20.1, R103.2
unnamed: D21.A, R105.1
unnamed: PWRLED20.1, R105.2
unnamed: I2CPU21.3, R107.2
unnamed: I2CPU21.1, R108.2
unnamed: D22.A, R110.1
unnamed: PWRLED21.1, R110.2
unnamed: I2CPU22.3, R112.2
unnamed: I2CPU22.1, R113.2
unnamed: D23.A, R115.1
unnamed: PWRLED22.1, R115.2
unnamed: I2CPU23.3, R117.2
unnamed: I2CPU23.1, R118.2
unnamed: D24.A, R120.1
unnamed: PWRLED23.1, R120.2
unnamed: I2CPU24.3, R122.2
unnamed: I2CPU24.1, R123.2
unnamed: D25.A, R125.1
unnamed: PWRLED24.1, R125.2
unnamed: I2CPU25.3, R127.2
unnamed: I2CPU25.1, R128.2
unnamed: D26.A, R130.1
unnamed: PWRLED25.1, R130.2
unnamed: I2CPU26.3, R132.2
unnamed: I2CPU26.1, R133.2
unnamed: D27.A, R135.1
unnamed: PWRLED26.1, R135.2
unnamed: I2CPU27.3, R137.2
unnamed: I2CPU27.1, R138.2
unnamed: D28.A, R140.1
unnamed: PWRLED27.1, R140.2
unnamed: I2CPU28.3, R142.2
unnamed: I2CPU28.1, R143.2
unnamed: D29.A, R145.1
unnamed: PWRLED28.1, R145.2
unnamed: I2CPU29.3, R147.2
unnamed: I2CPU29.1, R148.2
unnamed: D30.A, R150.1
unnamed: PWRLED29.1, R150.2
unnamed: I2CPU30.3, R152.2
unnamed: I2CPU30.1, R153.2
unnamed: D31.A, R155.1
unnamed: PWRLED30.1, R155.2
unnamed: I2CPU31.3, R157.2
unnamed: I2CPU31.1, R158.2
unnamed: D32.A, R160.1
unnamed: PWRLED31.1, R160.2
unnamed: I2CPU32.3, R162.2
unnamed: I2CPU32.1, R163.2
unnamed: D33.A, R165.1
unnamed: PWRLED32.1, R165.2
unnamed: I2CPU33.3, R167.2
unnamed: I2CPU33.1, R168.2
unnamed: D34.A, R170.1
unnamed: PWRLED33.1, R170.2
unnamed: I2CPU34.3, R172.2
unnamed: I2CPU34.1, R173.2
unnamed: D35.A, R175.1
unnamed: PWRLED34.1, R175.2
SCK/SCL: J1.4, J2.4, J5.4, J7.4, R4.1, U1.4
SCK/SCL1: J3.4, J4.4, J6.4, J8.4, R8.1, U2.4
SCK/SCL2: J9.4, J10.4, J11.4, J12.4, R13.1, U3.4
SCK/SCL3: J13.4, J14.4, J15.4, J16.4, R18.1, U4.4
SCK/SCL4: J17.4, J18.4, J19.4, J20.4, R23.1, U5.4
SCK/SCL5: J21.4, J22.4, J23.4, J24.4, R28.1, U6.4
SCK/SCL6: J25.4, J26.4, J27.4, J28.4, R33.1, U7.4
SCK/SCL7: J29.4, J30.4, J31.4, J32.4, R38.1, U8.4
SCK/SCL8: J33.4, J34.4, J35.4, J36.4, R43.1, U9.4
SCK/SCL9: J37.4, J38.4, J39.4, J40.4, R48.1, U10.4
SCK/SCL10: J41.4, J42.4, J43.4, J44.4, R53.1, U11.4
SCK/SCL11: J45.4, J46.4, J47.4, J48.4, R58.1, U12.4
SCK/SCL12: J49.4, J50.4, J51.4, J52.4, R63.1, U13.4
SCK/SCL13: J53.4, J54.4, J55.4, J56.4, R68.1, U14.4
SCK/SCL14: J57.4, J58.4, J59.4, J60.4, R73.1, U15.4
SCK/SCL15: J61.4, J62.4, J63.4, J64.4, R78.1, U16.4
SCK/SCL16: J65.4, J66.4, J67.4, J68.4, R83.1, U17.4
SCK/SCL17: J69.4, J70.4, J71.4, J72.4, R88.1, U18.4
SCK/SCL18: J73.4, J74.4, J75.4, J76.4, R93.1, U19.4
SCK/SCL19: J77.4, J78.4, J79.4, J80.4, R98.1, U20.4
SCK/SCL20: J81.4, J82.4, J83.4, J84.4, R103.1, U21.4
SCK/SCL21: J85.4, J86.4, J87.4, J88.4, R108.1, U22.4
SCK/SCL22: J89.4, J90.4, J91.4, J92.4, R113.1, U23.4
SCK/SCL23: J93.4, J94.4, J95.4, J96.4, R118.1, U24.4
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

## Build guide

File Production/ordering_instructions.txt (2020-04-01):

panel size, 143x188mm
PCB thickness, 1.6mm
number of layers, 2
soldermask color, Red
silkscreen color, White
oz copper, 1oz
finish, HASL lead free
stencils, top
pcs per panel, 35
min trace width, 0.1778mm / 0.0070in
min drill size, 0.3810mm / 0.0150in

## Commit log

2020-03-30 adding buzzard for address
    [Qwiic Environmental BME680.brd]
2020-03-31 pre design review changes
    [Qwiic Environmental BME680.brd, Qwiic Environmental BME680.sch]
2020-03-31 post checklist/review changes
    [Qwiic Environmental BME680.brd, Qwiic Environmental BME680.sch]
2020-04-01 adding panel
    [Qwiic Environmental BME680-Panel.GBL, Qwiic Environmental BME680-Panel.GBO, Qwiic Environmental BME680-Panel.GBP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]
2020-05-13 Update README
    Adding product photo and link to BME680 Arduino Library.

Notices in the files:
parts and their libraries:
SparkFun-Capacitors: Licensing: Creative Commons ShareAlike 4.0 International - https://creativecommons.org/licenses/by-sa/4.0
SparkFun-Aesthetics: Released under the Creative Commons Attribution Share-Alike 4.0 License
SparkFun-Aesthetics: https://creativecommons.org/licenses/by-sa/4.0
